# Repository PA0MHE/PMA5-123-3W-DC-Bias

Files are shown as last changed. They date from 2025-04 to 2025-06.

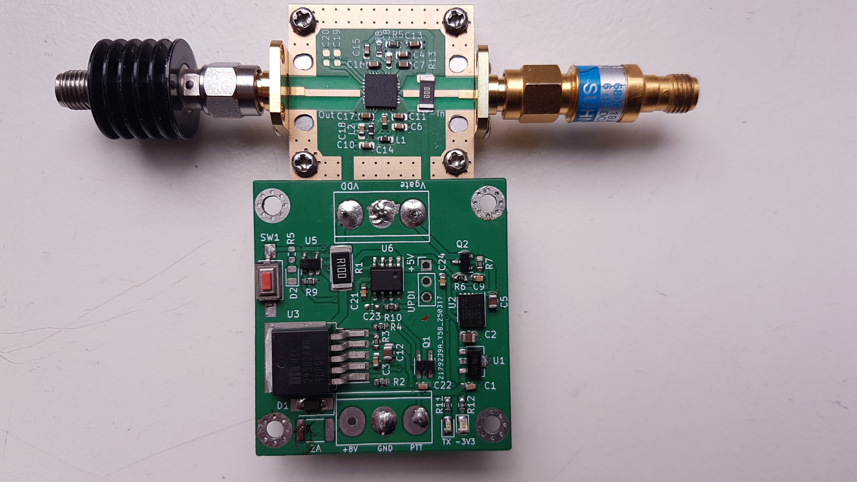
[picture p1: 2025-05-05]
PMA5-123-3W_DC.jpg

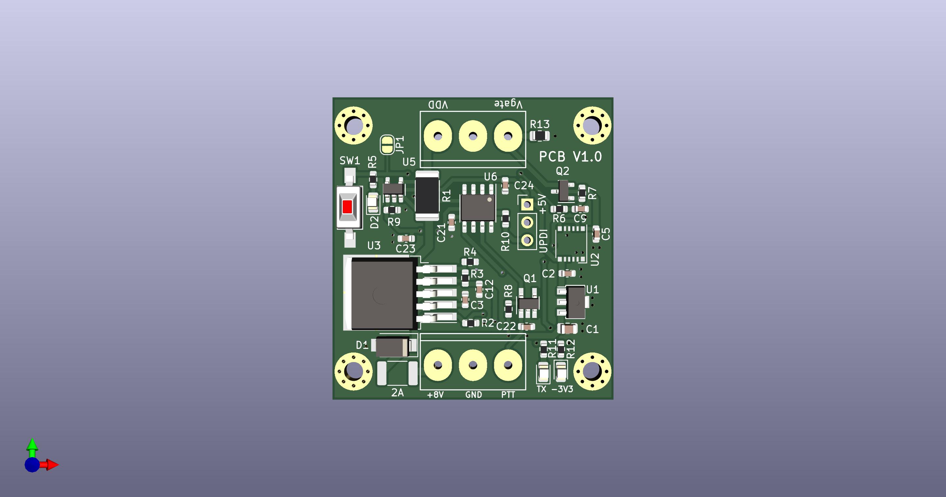
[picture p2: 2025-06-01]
PMA5-123-3W_DC_V1.0.jpg

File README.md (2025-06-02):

# PMA5-123-3W--DC-Bias

 DC bias PCB for PMA5-123-3W MMIC 3W 10GHz
 - ATtiny412 SW controlled
 - LDO for VDD, typical 7V
 - Switch to switch off or on Vdd
 - Idd Current measurment
 - DAC controlled (negative) Vgg powersupply
 - Inputs:
	+8 .. 12V DC
	PTT
 - Outputs
	Vdd
	Vgg (-1.5 .. -0.75V

# Key components:

	Attiny412
	MIC29302
	R05C1TF05S-R
	INA168

 # SW
	
	Uses megatinyCore in boardmanager
	Chip: ATtiny412
	clock: 8 MHz internal
	Programmer: serialUPDI 230400 baud

 By pressing SW1 during Power-Up, Idq is set to ~400mA and stored in EEPROM
 	
 HEX file is included.

# PCB

Gerber files are included, PCB's can be ordered at JCL PCB 

# Software

A V1.0 of the Control software is included.

# Disclaimer  

"This software and hardware design is provided "as is" and without  
any warranties, express or implied, including but not limited to the   
implied warranties of merchantability and fitness for a particular purpose." 
	
Normal operation:
During RX the Vgg is at around -1.5V and the Vdd is zero.
In TX the for 400mA Idq required bias voltage is applied at Vgg
	
First time use / calibration:
When SW1 is pressed during power up, the Idq is aligned at ~400mA, the required Vgg value is stored in non volatile memory.
When this above calibration is not done, the a Vgg minimum value of ~ -1.5V is always applied.

73's

Maarten PA0MHE, Rens PA3AXA

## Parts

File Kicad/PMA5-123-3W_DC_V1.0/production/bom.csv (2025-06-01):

Designator | Footprint | Quantity | Value | LCSC Part #
C1 | 0805 | 1 | 10u
C12, C2, C5 | 0603 | 3 | 10u
C21, C22, C24, C3, C9 | 0603 | 5 | 100n
C23 | 0603 | 1 | Opt
D1 | D_SMA | 1 | SS34
D2 | 0805 | 1 | Blue LED
D3 | 0805 | 1 | Red LED
D4 | 0805 | 1 | Green LED
F1 | 1812 | 1 | 2A
H2, H3, H5, H6 | MountingHole_2.7mm_M2.5_Pad_Via | 4 | ~
J1 | KF301-3P | 1 | 8V-DC
J2 | PinHeader_1x03_P2.54mm_Vertical | 1 | UPDI
J3 | KF301-3P | 1 | RF_unit
JP1 | SolderJumper-2_P1.3mm_Open_RoundedPad1.0x1.5mm | 1 | '
Q1 | SOT-25_HandSoldering | 1 | FMG1
Q2 | SOT-23 | 1 | BC859C
R1 | 2512 | 1 | 0.1R
R10, R4 | 0603 | 2 | 470R
R11 | 0603 | 1 | 1K
R12 | 0603 | 1 | 330R
R13 | 0805 | 1 | 100R
R2 | 0603 | 1 | 4K7
R3 | 0603 | 1 | 2K2
R5, R8 | 0603 | 2 | 10K
R6 | 0603 | 1 | 5K1
R7 | 0603 | 1 | 2K
R9 | 0603 | 1 | 51K
SW1 | SW_SPST_FSMSM | 1 | SW_Push
U1 | SOT-89-3 | 1 | L78L05_SOT89
U2 | R05C1TF05S | 1 | R05C1TF05S-R
U3 | TO-263-5_TabPin3 | 1 | MIC29302
U5 | SOT-23-5 | 1 | INA168
U6 | SOIC-8_3.9x4.9mm_P1.27mm | 1 | ATtiny412-SS

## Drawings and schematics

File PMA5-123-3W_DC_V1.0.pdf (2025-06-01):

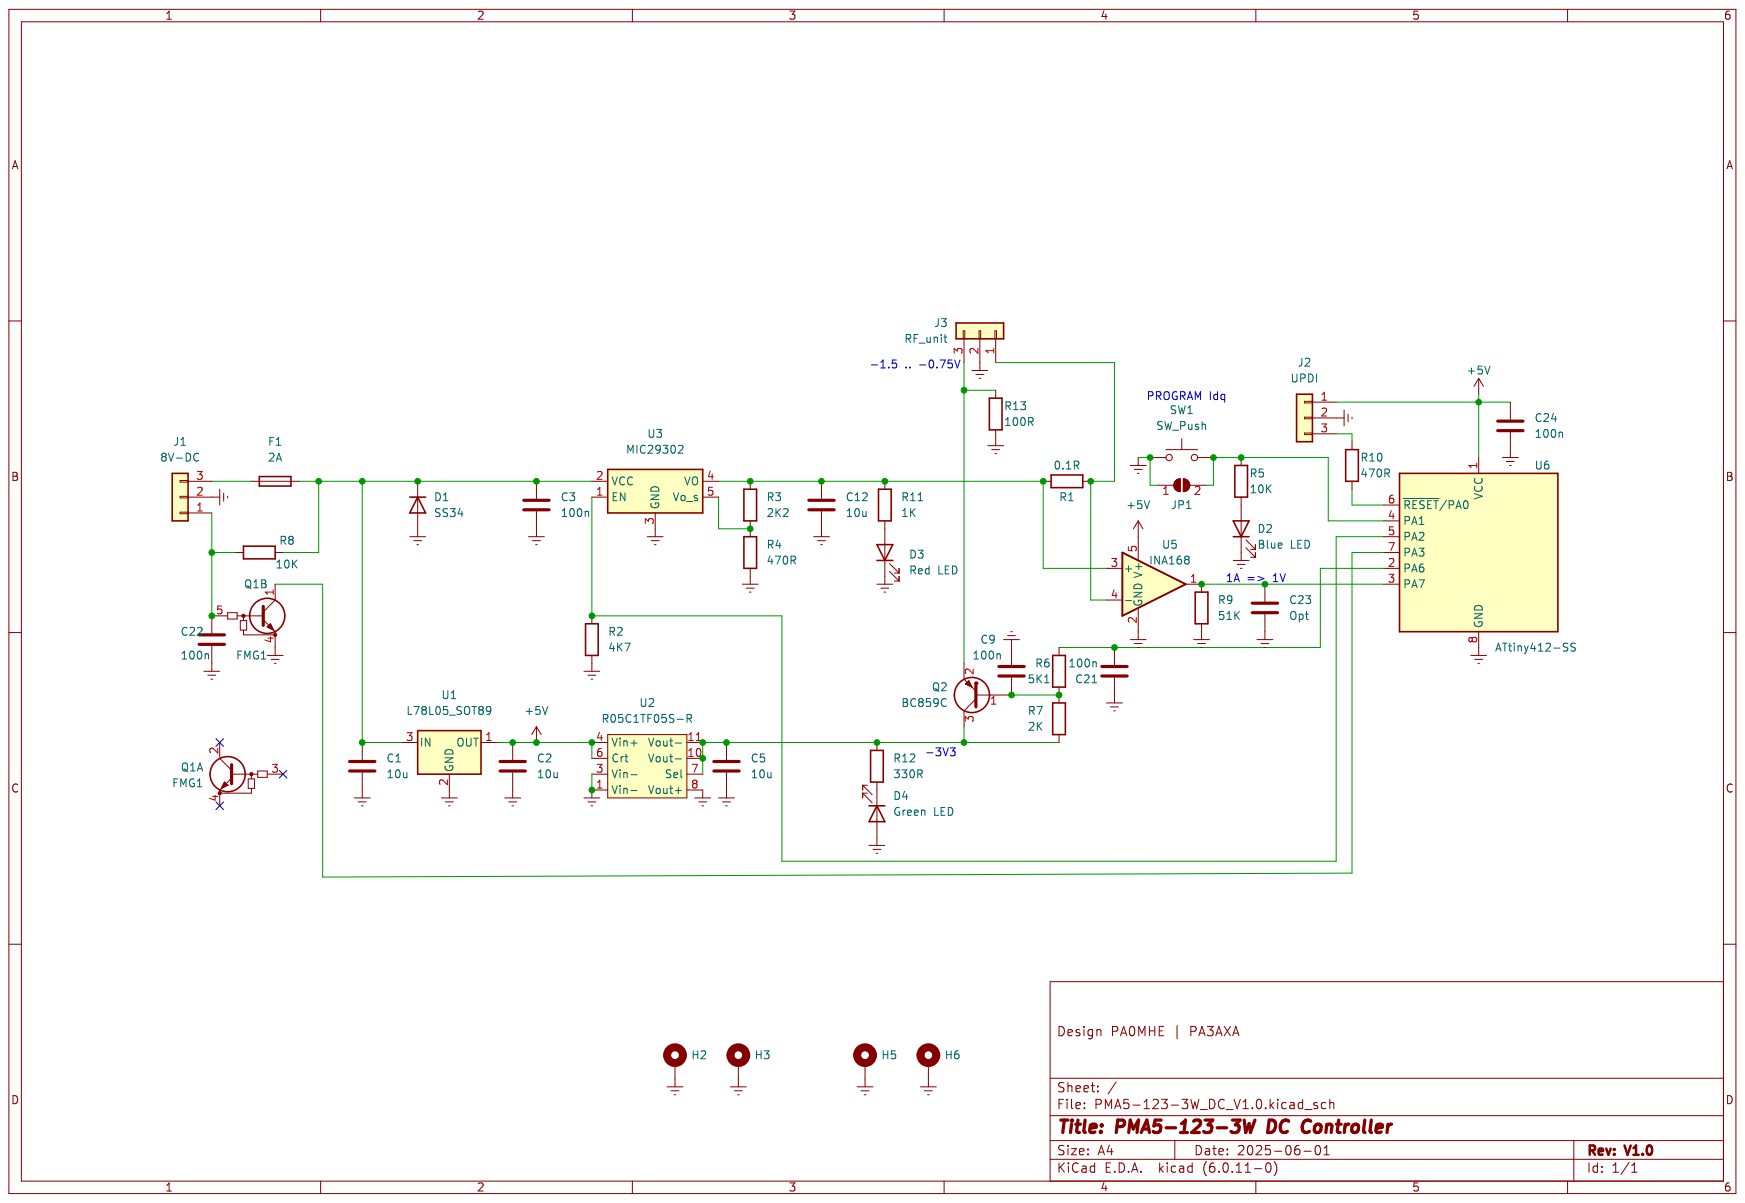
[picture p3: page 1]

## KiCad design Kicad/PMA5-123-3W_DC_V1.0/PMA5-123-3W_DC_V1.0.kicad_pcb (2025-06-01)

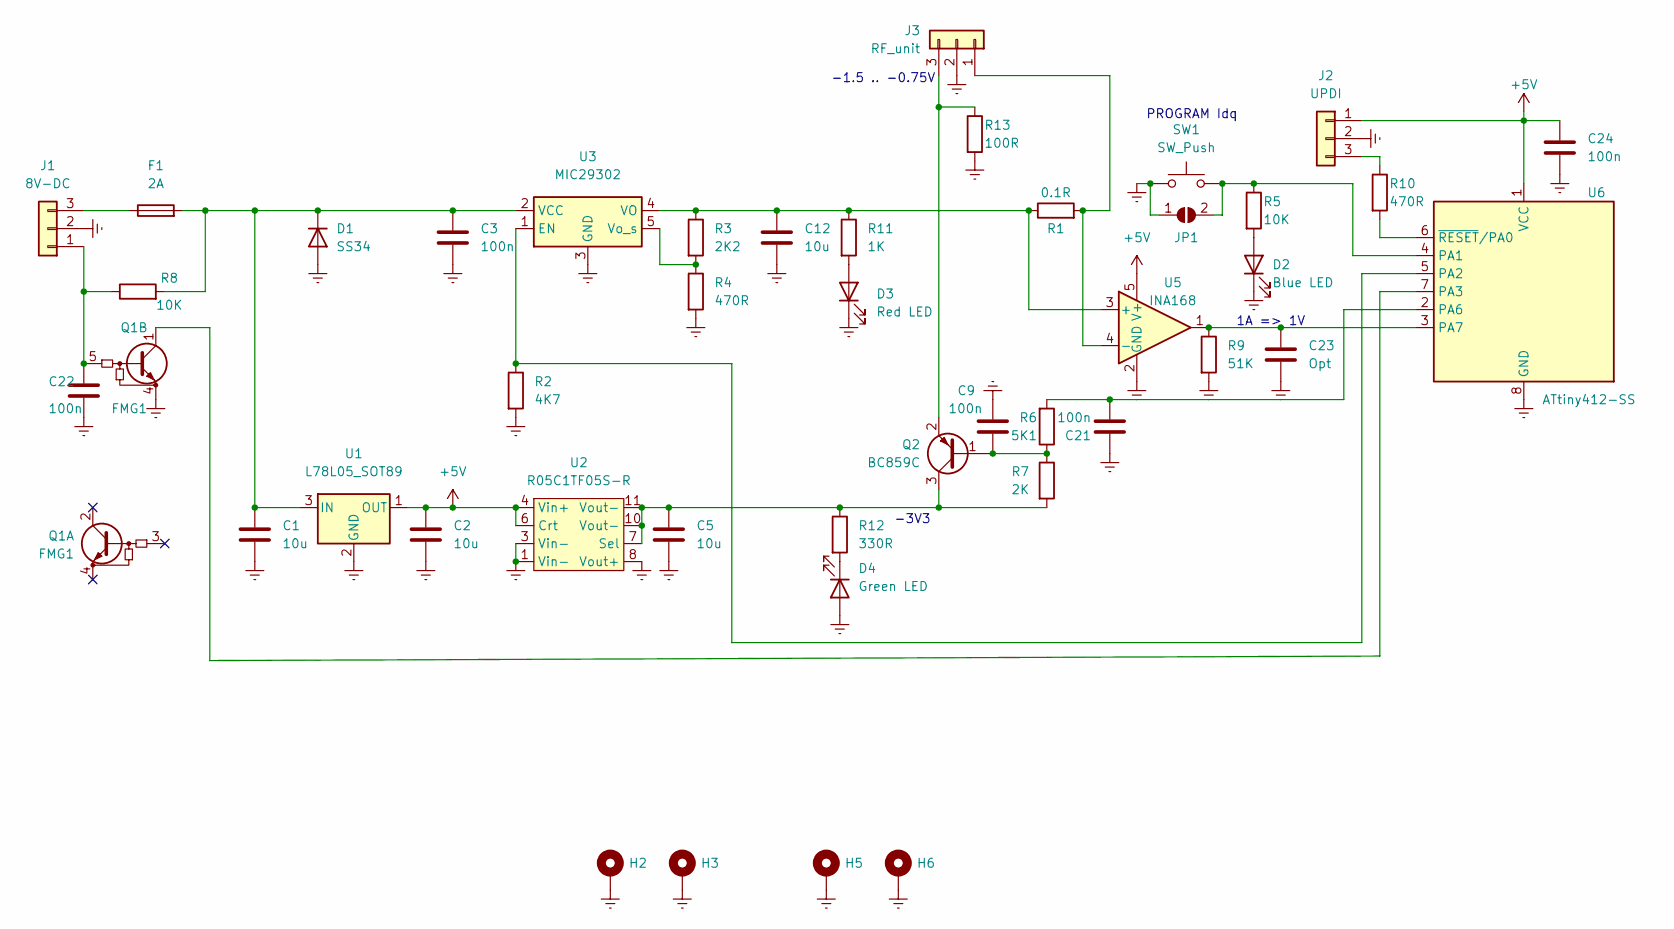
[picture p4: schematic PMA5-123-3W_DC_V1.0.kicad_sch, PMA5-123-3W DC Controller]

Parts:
C1: 10u; C_0805_2012Metric
C2, C5, C12: 10u; C_0603_1608Metric
C3, C9, C21, C22, C24: 100n; C_0603_1608Metric
C23: Opt; C_0603_1608Metric
D1: SS34; D_SMA; Mouser 750-SS34BF
D2: Blue LED; LED_0805_2012Metric
D3: Red LED; LED_0805_2012Metric
D4: Green LED; LED_0805_2012Metric
F1: 2A; Fuse_1812_4532Metric_Pad1.30x3.40mm_HandSolder; Mouser 576-1812L200/12DR
H2, H3, H5, H6: MountingHole_2.7mm_M2.5_Pad_Via
J1: 8V-DC; KF301-3P
J2: UPDI; PinHeader_1x03_P2.54mm_Vertical
J3: RF_unit; KF301-3P
JP1: '; SolderJumper-2_P1.3mm_Open_RoundedPad1.0x1.5mm
Q1: FMG1; SOT-25_HandSoldering; Mouser 755-FMG1AT148
Q2: BC859C; SOT-23
R1: 0.1R; R_2512_6332Metric; Mouser 603-PT2512FK-070R1L
R2: 4K7; R_0603_1608Metric
R3: 2K2; R_0603_1608Metric
R4, R10: 470R; R_0603_1608Metric
R5, R8: 10K; R_0603_1608Metric
R6: 5K1; R_0603_1608Metric
R7: 2K; R_0603_1608Metric
R9: 51K; R_0603_1608Metric
R11: 1K; R_0603_1608Metric
R12: 330R; R_0603_1608Metric
R13: 100R; R_0805_2012Metric
SW1: SW_Push; SW_SPST_FSMSM
U1: L78L05_SOT89; SOT-89-3; Mouser 511-L78L05ABU
U2: R05C1TF05S-R; R05C1TF05S; Mouser 919-R05C1TF05S-R
U3: MIC29302; TO-263-5_TabPin3; Mouser 998-MIC29302WU
U5: INA168; SOT-23-5; Mouser 595-INA168NA/3K
U6: ATtiny412-SS; SOIC-8_3.9x4.9mm_P1.27mm; Mouser 579-ATTINY412-SSF

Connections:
+5V: C2.1, C24.1, J2.1, U1.1 (OUT), U2.4 (Vin+), U2.5 (Vin+), U2.6 (Crt), U5.5 (V+), U6.1 (VCC)
GNDREF: C1.2, C2.2, C3.2, C5.2, C9.1, C12.2, C21.1, C22.2, C23.2, C24.2, D1.2 (A), D2.1 (K), D3.1 (K), D4.2 (A), H2.1, H3.1, H5.1, H6.1, J1.2, J2.2, J3.2, JP1.1 (A), Q1.4 (E1), R2.2, R4.2, R9.2, R13.2, SW1.1, U1.2 (GND), U2.1 (Vin-), U2.2 (Vin-), U2.3 (Vin-), U2.8 (Vout+), U2.9 (Vout+), U3.3 (GND), U5.2 (GND), U6.8 (GND)
unnamed: C1.1, C3.1, D1.1 (K), F1.2, R8.2, U1.3 (IN), U3.2 (VCC)
unnamed: C5.1, Q2.3 (C), R7.2, R12.1, U2.7 (Sel), U2.10 (Vout-), U2.11 (Vout-), U2.12 (Vout-)
unnamed: C9.2, Q2.1 (B), R6.1, R7.1
unnamed: C12.1, R1.1, R3.1, R11.1, U3.4 (VO), U5.3 (+)
unnamed: C21.2, R6.2, U6.2 (PA6)
unnamed: C22.1, J1.1, Q1.5 (B1), R8.1
unnamed: C23.1, R9.1, U5.1, U6.3 (PA7)
unnamed: D2.2 (A), R5.2
unnamed: D3.2 (A), R11.2
unnamed: D4.1 (K), R12.2
unnamed: F1.1, J1.3
unnamed: J2.3, R10.1
unnamed: J3.1, R1.2, U5.4 (-)
unnamed: J3.3, Q2.2 (E), R13.1
unnamed: JP1.2 (B), R5.1, SW1.2, U6.4 (PA1)
unnamed: Q1.1 (C1), U6.7 (PA3)
unnamed: R2.1, U3.1 (EN), U6.5 (PA2)
unnamed: R3.2, R4.1, U3.5 (Vo_s)
unnamed: R10.2, U6.6 (~RESET/PA0)

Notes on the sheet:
PROGRAM Idq
-3V3
-1.5 .. -0.75V
1A => 1V

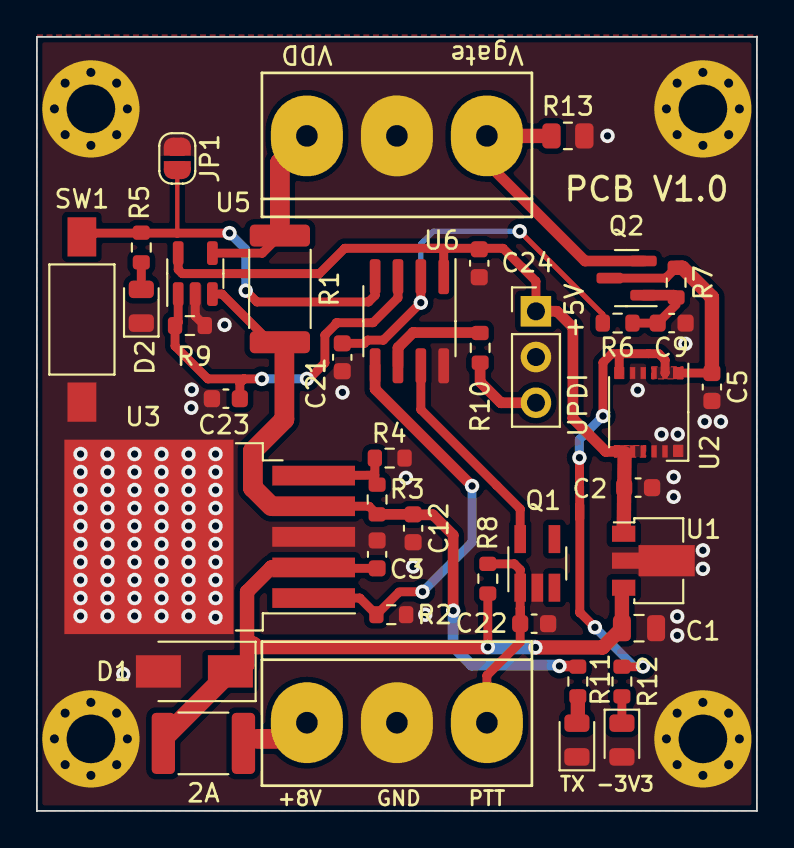
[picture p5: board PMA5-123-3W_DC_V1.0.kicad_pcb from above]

Board: 2 copper layers, 40.0 x 43.0 mm, 44 parts (0 on the bottom side), 21 nets.

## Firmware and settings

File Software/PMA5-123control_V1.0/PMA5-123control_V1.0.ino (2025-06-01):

/* DC control Minicircuit PMA5-123-3W+ 
 *  ------------------------------------------
 *         3W 10GHz GaAs MMIC
 *         
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
 *  
 * Rens PA3AXA / Maarten PA0MHE
 * 
 * Software V1.0 - Initial release 01-06-2025 for
 * Hardware V1.0 - Initial release 01-06-2025
 * 
 * Uses megatinyCore in boardmanager
 * Chip: ATtiny412
 * Clock: 8 MHz internal
 * Safe EEprom setting to retain set Bias
 * Programmer: serialUPDI 230400 baud
 * 
 * 
 * Current sensor gain R9 is set for 51k ohm
 * this nearly 1A/V.
 * 
 *    1.02V = (1) (0,1) (200 μA/V) (51k)
 
 
 ----------------------------------------------------------------
    
     ###  ### #   #  ###
    #   #  #  ##  # #
    ####   #  # # #  ###
    #      #  #  ##     #
    #     ### #   #  ###

 ----------------------------------------------------------------
*/

#include <EEPROM.h>
 
#define pttPin     PIN_PA3 // package pin 7 on AtTiny 412
#define vddEnable  PIN_PA2 // package pin 5
#define IdADC      PIN_PA7 // package pin 3
#define switchPin  PIN_PA1 // package pin 4
#define VggDAC     PIN_PA6 // DAC It must be package pin 2

#define VggMin  90         // DAC value for lowest Vgate useally -1.5V
#define VggMax 255         // DAC value for highest Vgate -0.73V

/* Vgg 0 = -1,9V, Vgg 90 = -1.5 Vgg 255 = -0,73,  Vgg 128 = -1.37V */ 

#define Idq    163         //  400mA ADC  0,4/2,5 * 1023 = 163
#define IdMax  511         // 1250mA ADC 1,25/2,5 * 1023 = 511
#define IdMin  0           //    0mA ADC  0,2/2.5 * 1023 = 0

/* The IdMin feature is not fully tested current default 0 mA */


#define VggEeprom 1
#define IdEeprom 2

#define EepromProgrammed 0x55

bool TX = false;
bool error = false;
bool LedState = false;

int VggIdq = 150;         // DAC value before calibration set to a safe value


void setup(){
  
  digitalWrite(vddEnable, LOW);   // 7V VDD of PMA5-123 is OFF 
  pinMode(vddEnable, OUTPUT);

  DACReference(INTERNAL4V3);     // DAC reference, max 8bit level is 4,3V 
  analogReference(INTERNAL2V5);  // 10bit ADC, Input > Ref is clipped to 0x3FF = 1023

  pinMode(pttPin, INPUT_PULLUP);
  pinMode(switchPin, INPUT_PULLUP);

  analogWrite(VggDAC, VggMin);   // Write DAC cut Vgg Drain Cut-off level

  delay(500);
 
 /*
  Press Switch during Power-Up to Start Idq callibration
  Final VggIdq value is set to meet the Idq of 400mA
 */
 
  if (!digitalRead(switchPin)){
  SetIdq();
  }

  
 /*Check if we need to run calibration, (needed after every software update) */
  
  if (EEPROM.read(IdEeprom) != EepromProgrammed) {
        EEPROM.write(VggEeprom, VggMin);
        
        // Switch to output mode for error flash
        pinMode(switchPin, OUTPUT);
        
        for (int c=0; c < 6; c++) {
        delay(100);
        LedState = !LedState;
        digitalWrite(switchPin, LedState); // Flash 5x to sign EEProm is not programmmed   
        }
        pinMode(switchPin, INPUT_PULLUP); 
    }
  
  /* Load VggIdq setting for the idle current */
  
  VggIdq = EEPROM.read(VggEeprom);     

}



void loop(){
    
    if (TX) { // Check if RX mode requested when in TX
      if (!digitalRead(pttPin)) { // RX mode requested when pptPin == Low
      SwitchOffPA();
      TX = false;
      }
    }
    
    if (!TX) { // Check if TX mode requested when in RX
       if (digitalRead(pttPin)) { // TX mode requested when pptPin == High
        SwitchOnPA();
        TX = true;
      }
    }

   // System Error detect check if currents are between normal operation parms
   
   if (TX) {
      if ((analogRead(IdADC) > IdMax) || (analogRead(IdADC) < IdMin )) {
      SwitchOffPA();
      TX = false;
      SysError(1000); // Flash LED every second
      }
   }

}// End Loop


void SysError(int t){

  // Flash LED when we are in error needs powerdown to reset
  pinMode(switchPin, OUTPUT);  
  
  while (true){
  delay(t);
  LedState = !LedState;
  digitalWrite(switchPin, LedState);
 }
} 

void SwitchOnPA(){
  
  analogWrite(VggDAC, VggMin);
  delay(100); 
  digitalWrite(vddEnable, HIGH);   // 7V VDD of PMA5-123 is ON 
  delay(100); 
  analogWrite(VggDAC, VggIdq);
  delay(100);
  if ((analogRead(IdADC) > IdMax) || (analogRead(IdADC) < IdMin )) {
  SwitchOffPA();
  SysError(100);
  }

} // END SwitchOnPA


void SwitchOffPA() {
  
  analogWrite(VggDAC, VggMin);  // First Vgg to MIN  to cut drain current
  delay(100); 
  digitalWrite(vddEnable, LOW);    // 7V VDD of PMA5-123 is OFF
  delay(100); 
  
} // END SwitchOffPA


/*
 * Button start current setting only during Power-Up 
 */

void SetIdq(){

    analogWrite(VggDAC, VggMin);
    delay(100);
    digitalWrite(vddEnable, HIGH);   // 7V VDD of PMA5-123 is ON 
    delay(100);
    
    for (int i=VggMin; i < VggMax; i++)
    {
    analogWrite(VggDAC, i);
    delay(100);
      if (analogRead(IdADC) > Idq) // Idq setting reached, stop loop
        {
          delay(100);
          analogWrite(VggDAC, VggMin);
          delay(100);
          digitalWrite(vddEnable, LOW);   // 7V VDD of PMA5-123 is OFF
          delay(100);
          
          // Program Vgg in EEprom
          EEPROM.write(VggEeprom, i);
          EEPROM.write(IdEeprom, EepromProgrammed);
          break;
        }
    }
     
    // Turn off Calibrate Idq mode when not writing to EEprom.
    // This happens when Idq setting not satisfied.
    // Leave at current settings
      
    delay(100);
    analogWrite(VggDAC, VggMin);
    delay(100);
    digitalWrite(vddEnable, LOW);   // 7V VDD of PMA5-123 is OFF
    delay(100);
}

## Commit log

2025-04-18 Used right symbol in schematic
    [PMA5-123-3W_DConly.kicad_sch]
2025-05-05 Update Kicad and SW
    [PMA5-123-3W_DConly_v1.kicad_pcb, PMA5-123-3W_DConly_v1.kicad_sch]
2025-05-15 Changed symbol Q2
    [PMA5-123-3W_DConly_v1.kicad_pcb, PMA5-123-3W_DConly_v1.kicad_sch]
2025-05-15 Changed value
    [PMA5-123-3W_DConly_v1.kicad_sch]
2025-05-16 Added R13 and JP1
    [PMA5-123-3W_DConly_v1.kicad_pcb, PMA5-123-3W_DConly_v1.kicad_sch]
2025-06-01 Update to version V1.0
    [PMA5-123-3W_DC_V1.0.kicad_pcb, PMA5-123-3W_DC_V1.0.kicad_sch, bom.csv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]
2025-06-01 Kicad closed update
    [PMA5-123-3W_DC_V1.0.kicad_pcb, PMA5-123-3W_DC_V1.0.kicad_sch]
2025-06-01 Remove Kicad BackUp Files
2025-06-02 added calibration in readme
